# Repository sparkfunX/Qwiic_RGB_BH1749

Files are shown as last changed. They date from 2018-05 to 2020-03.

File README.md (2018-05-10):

SparkFun RGB Sensor (Qwiic) - BH1749NUC
========================================

SparkFun RGB Sensor (Qwiic) - BH1749NUC

[*SparkX RGB Sensor (Qwiic) - BH1749NUC (SPX-14733)*](https://www.sparkfun.com/products/14733)

Need to autonomously monitor for that specific color value? Want to hone in on that magenta ball? Or follow that aquamarine line? The BH1749NUC-based Qwiic RGB Sensor is here for all of your <span style="color:red">red</span>, <span style="color:green">green</span>, <span style="color:blue">blue</span>, and <span style="color:darkred">infrared</span> color-sensing needs.

The **BH1749NUC** features an I<sup>2</sup>C interface and a programmable interrupt output. It senses red, green, blue, and infrared in its field-of-view, then reports them as a 16-bit value. Additionally, it features programmable IR and RGB gains and a variable measurement rate. 

Also included on the breakout are individually-controllable white, red, green, and blue LEDs. The LEDs are managed with a **PCA9536** 4-channel I/O I<sup>2</sup>C expander. We've got a library for that too!

Check out the documents section for a pair of Arduino libraries -- for both the [BH1749NUC](https://github.com/sparkfun/SparkFun_BH1749NUC_Arduino_Library) and [PCA9536](https://github.com/sparkfun/SparkFun_PCA9536_Arduino_Library) IC's -- and a handful of examples to help get you started.

The Qwiic RGB Sensor uses our simple [Qwiic](https://www.sparkfun.com/qwiic) interface, so it requires no voltage translation and no figuring out which pin is SDA or SCL; just plug it in and go! As with any Qwiic board, this product includes a pair of Qwiic connectors to support a chain of multiple sensors.

SparkFun labored with love to create this code. Feel like supporting open source hardware? 
Buy a [breakout board](https://www.sparkfun.com/products/14733) from SparkFun!

Repository Contents
-------------------

* **/Documents** - Datasheets
* **/Hardware** - Eagle design files (.brd, .sch)

License Information
-------------------

This product is _**open source**_! 

If you have any questions or concerns on licensing, please contact techsupport@sparkfun.com.

Please use, reuse, and modify these files as you see fit. Please maintain attribution to SparkFun Electronics and release any derivative under the same license.

Distributed as-is; no warranty is given.

- Your friends at SparkFun.

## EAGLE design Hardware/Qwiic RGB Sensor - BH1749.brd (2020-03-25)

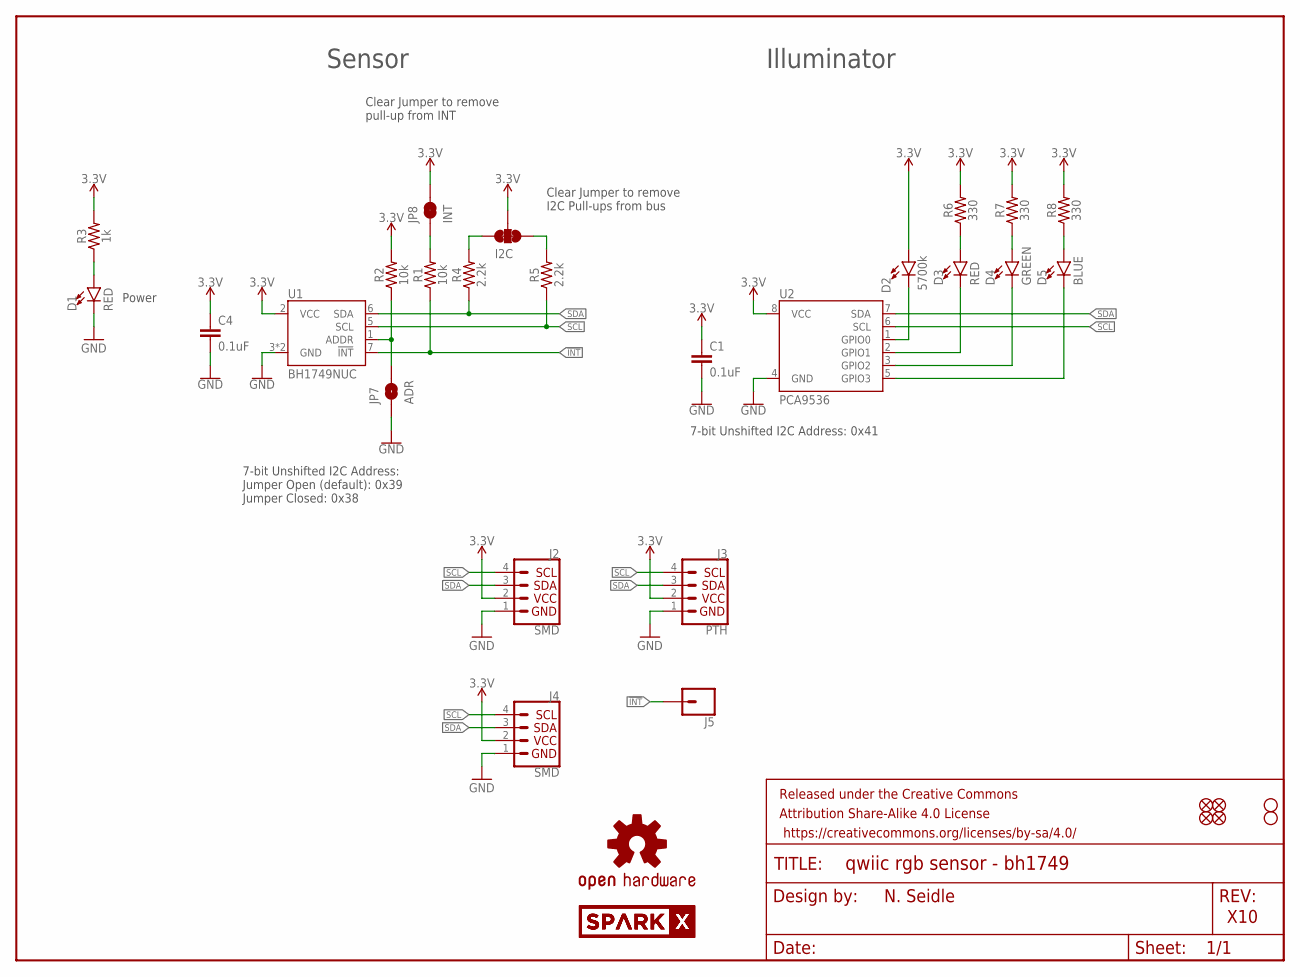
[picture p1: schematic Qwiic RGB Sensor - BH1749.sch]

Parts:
C1, C4: 0.1uF; 0603
D1, D3: RED; LED-0603
D2: 5700k; SUPER_BRIGHT_SMD_LED_1206
D4: GREEN; LED-0603
D5: BLUE; LED-0603
FRAME1: FRAME-LETTER; CREATIVE_COMMONS
I2C: JUMPER-SMT_3_2-NC_TRACE_SILK; SMT-JUMPER_3_2-NC_TRACE_SILK
J2, J4: SMD; 1X04_1MM_RA
J3: PTH; 1X04_NO_SILK
J5: CONN_01PTH_NO_SILK_YES_STOP; 1X01_NO_SILK
JP1, JP2, JP5, JP6: FIDUCIALUFIDUCIAL; MICRO-FIDUCIAL
JP3, JP4: STAND-OFF
JP7: ADR; SMT-JUMPER_2_NO_SILK
JP8: INT; SMT-JUMPER_2_NC_TRACE_SILK
LOGO1: OSHW-LOGOMINI; OSHW-LOGO-MINI
R1, R2: 10k; 0603
R3: 1k; 0603
R4, R5: 2.2k; 0603
R6, R7, R8: 330; 0603
U1: BH1749NUC
U2: PCA9536; MSOP8
U$1, U$2: SPARKX-LOGO4; SPARKX-MEDIUM

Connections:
3.3V: C1.1, C4.1, D2.A, I2C.2, J2.2 (VCC), J3.2 (VCC), J4.2 (VCC), JP8.2, R2.2, R3.2, R6.2, R7.2, R8.2, U1.2 (VCC), U2.8 (VCC)
!INT: J5.1, R1.1, U1.7 (!INT)
ADR: JP7.2, R2.1, U1.1 (ADDR)
GND: C1.2, C4.2, D1.C, J2.1 (GND), J3.1 (GND), J4.1 (GND), JP7.1, U1.3 (GND), U1.4 (GND), U2.4 (GND)
unnamed: I2C.1, R5.2
unnamed: I2C.3, R4.2
unnamed: D1.A, R3.1
unnamed: JP8.1, R1.2
unnamed: D3.C, U2.2 (GPIO1)
unnamed: D4.C, U2.3 (GPIO2)
unnamed: D5.C, U2.5 (GPIO3)
unnamed: D3.A, R6.1
unnamed: D4.A, R7.1
unnamed: D2.C, U2.1 (GPIO0)
unnamed: D5.A, R8.1
SCL: J2.4 (SCL), J3.4 (SCL), J4.4 (SCL), R5.1, U1.5 (SCL), U2.6 (SCL)
SDA: J2.3 (SDA), J3.3 (SDA), J4.3 (SDA), R4.1, U1.6 (SDA), U2.7 (SDA)

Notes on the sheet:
N. Seidle
X10
7-bit Unshifted I2C Address: Jumper Open (default): 0x39 Jumper Closed: 0x38
Clear Jumper to remove I2C Pull-ups from bus
Clear Jumper to remove pull-up from INT
Power
7-bit Unshifted I2C Address: 0x41
Sensor
Illuminator

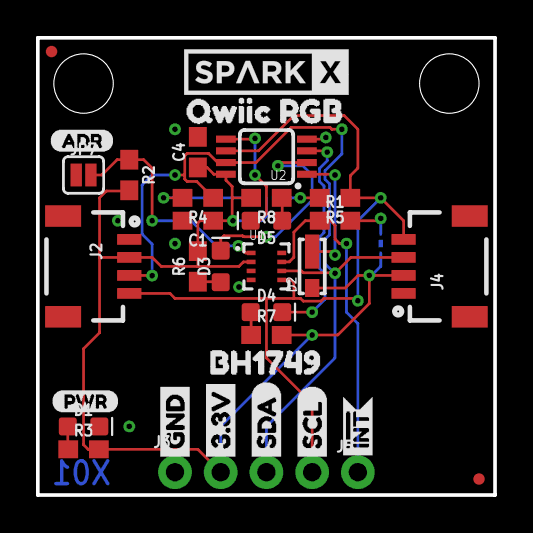
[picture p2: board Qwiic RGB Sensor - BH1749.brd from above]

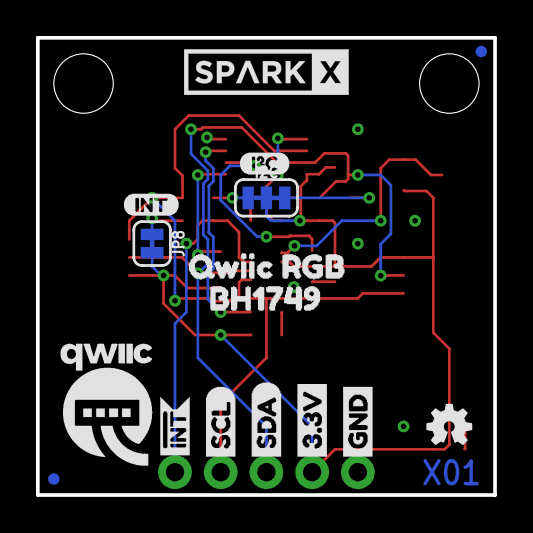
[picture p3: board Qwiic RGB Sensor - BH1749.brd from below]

Board: 2 copper layers, 25.4 x 25.4 mm, 53 parts (16 on the bottom side), 17 nets.

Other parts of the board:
U$3, U$22: GND1
U$4, U$21: 3#3V2
U$5, U$27: SDA8
U$6, U$26: SCL9
U$7, U$9: INT#-[<
U$8: QWIIC-LOGO-MEDIUM
U$10: I_SUPER2_C-()-03
U$11, U$13: BH17493
U$12, U$24: QWIIC_RGB2
U$16: PWR-()-03
U$17: ADR-()-03
U$20: INT0

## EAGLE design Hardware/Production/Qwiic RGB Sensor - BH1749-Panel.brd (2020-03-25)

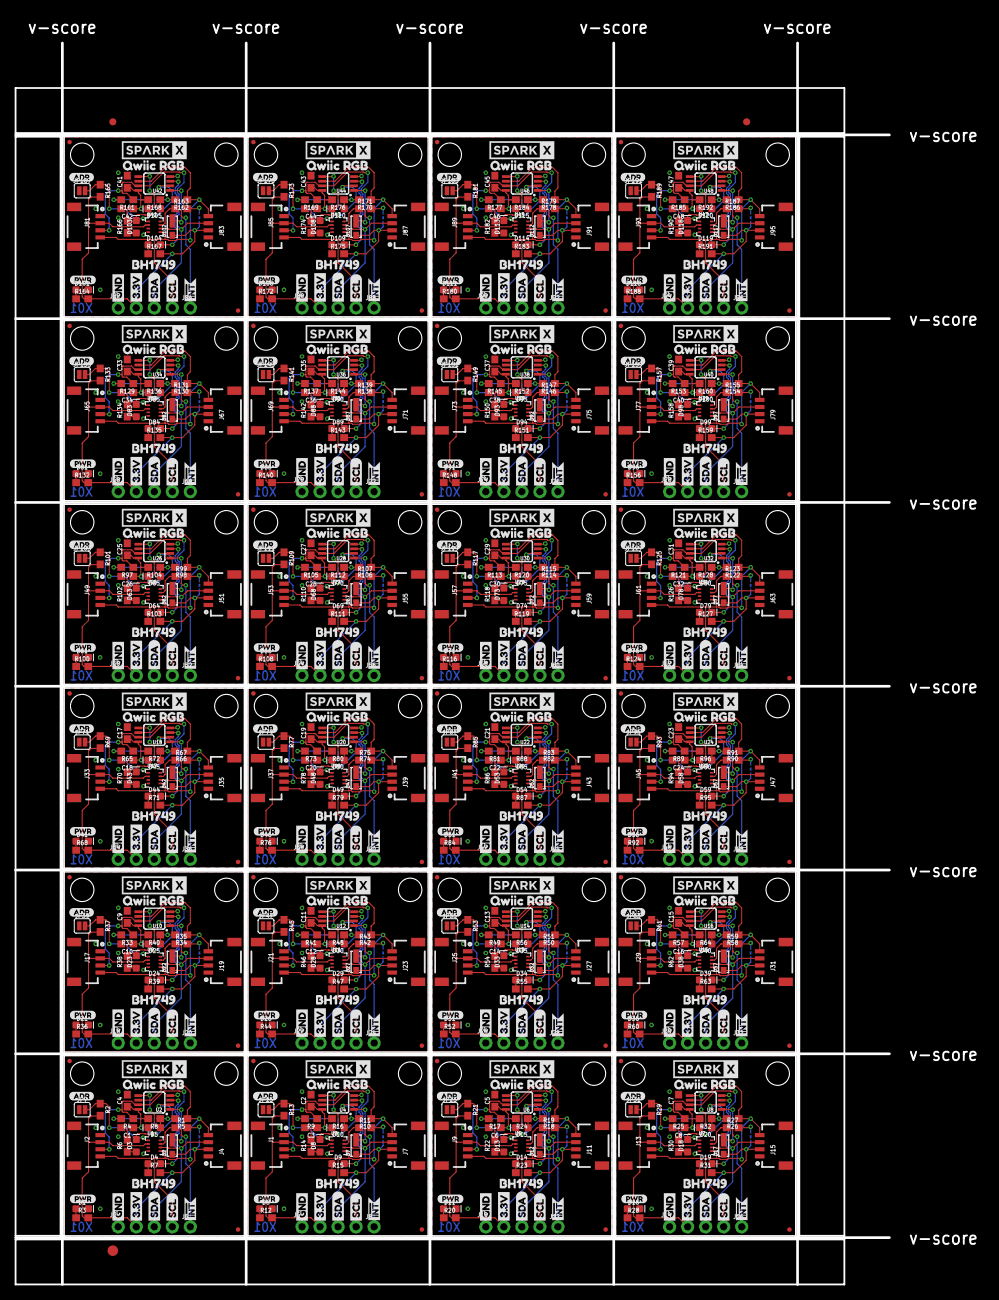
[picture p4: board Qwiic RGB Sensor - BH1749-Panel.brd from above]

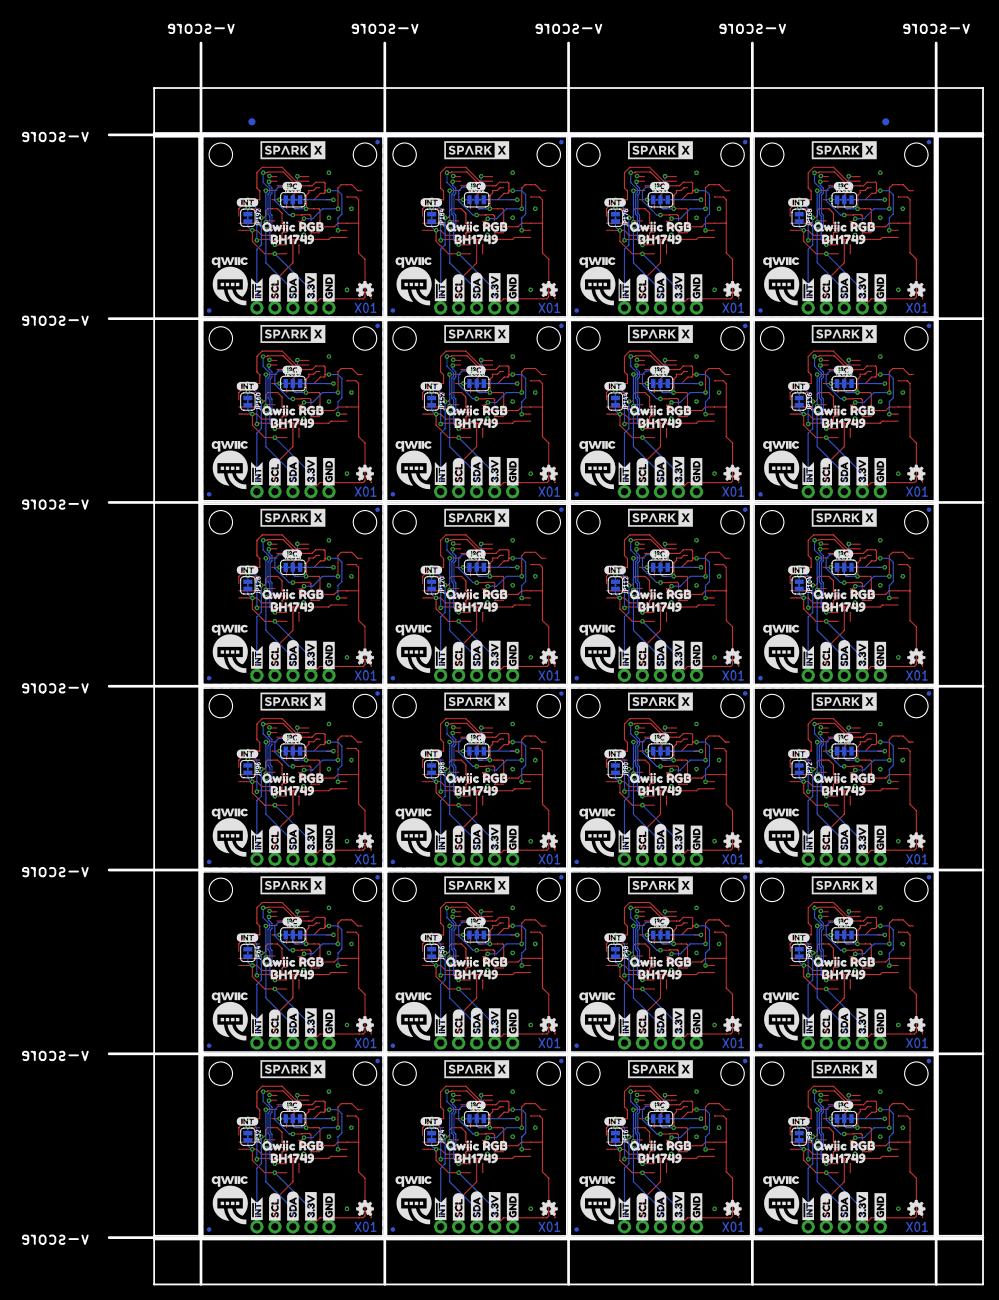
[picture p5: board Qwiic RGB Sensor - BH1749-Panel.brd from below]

Board: 2 copper layers, 123.2 x 175.0 mm, 1253 parts (386 on the bottom side), 408 nets.

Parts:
C1, C2, C3, C4, C5, C6, C7, C8, C9, C10, C11, C12, C13, C14, C15, C16, C17, C18, C19, C20, C21, C22, C23, C24, C25, C26, C27, C28, C29, C30, C31, C32, C33, C34, C35, C36, C37, C38, C39, C40, C41, C42, C43, C44, C45, C46, C47, C48: 0.1uF; 0603
D1, D3, D6, D8, D11, D13, D16, D18, D21, D23, D26, D28, D31, D33, D36, D38, D41, D43, D46, D48, D51, D53, D56, D58, D61, D63, D66, D68, D71, D73, D76, D78, D81, D83, D86, D88, D91, D93, D96, D98, D101, D103, D106, D108, D111, D113, D116, D118: RED; LED-0603
D2, D7, D12, D17, D22, D27, D32, D37, D42, D47, D52, D57, D62, D67, D72, D77, D82, D87, D92, D97, D102, D107, D112, D117: 5700k; SUPER_BRIGHT_SMD_LED_1206
D4, D9, D14, D19, D24, D29, D34, D39, D44, D49, D54, D59, D64, D69, D74, D79, D84, D89, D94, D99, D104, D109, D114, D119: GREEN; LED-0603
D5, D10, D15, D20, D25, D30, D35, D40, D45, D50, D55, D60, D65, D70, D75, D80, D85, D90, D95, D100, D105, D110, D115, D120: BLUE; LED-0603
E$1, E$2, E$3, E$4: FIDUCIAL-1X2
E$5: FIDUCIAL-1.5X3
I2C, I2C1, I2C2, I2C3, I2C4, I2C5, I2C6, I2C7, I2C8, I2C9, I2C10, I2C11, I2C12, I2C13, I2C14, I2C15, I2C16, I2C17, I2C18, I2C19, I2C20, I2C21, I2C22, I2C23: SMT-JUMPER_3_2-NC_TRACE_SILK
J1, J2, J4, J7, J9, J11, J13, J15, J17, J19, J21, J23, J25, J27, J29, J31, J33, J35, J37, J39, J41, J43, J45, J47, J49, J51, J53, J55, J57, J59, J61, J63, J65, J67, J69, J71, J73, J75, J77, J79, J81, J83, J85, J87, J89, J91, J93, J95: SMD; 1X04_1MM_RA
J3, J6, J10, J14, J18, J22, J26, J30, J34, J38, J42, J46, J50, J54, J58, J62, J66, J70, J74, J78, J82, J86, J90, J94: PTH; 1X04_NO_SILK
J5, J8, J12, J16, J20, J24, J28, J32, J36, J40, J44, J48, J52, J56, J60, J64, J68, J72, J76, J80, J84, J88, J92, J96: 1X01_NO_SILK
JP1, JP2, JP5, JP6, JP11, JP12, JP13, JP14, JP19, JP20, JP21, JP22, JP27, JP28, JP29, JP30, JP35, JP36, JP37, JP38, JP43, JP44, JP45, JP46, JP51, JP52, JP53, JP54, JP59, JP60, JP61, JP62, JP67, JP68, JP69, JP70, JP75, JP76, JP77, JP78, JP83, JP84, JP85, JP86, JP91, JP92, JP93, JP94, JP99, JP100, JP101, JP102, JP107, JP108, JP109, JP110, JP115, JP116, JP117, JP118, JP123, JP124, JP125, JP126, JP131, JP132, JP133, JP134, JP139, JP140, JP141, JP142, JP147, JP148, JP149, JP150, JP155, JP156, JP157, JP158, JP163, JP164, JP165, JP166, JP171, JP172, JP173, JP174, JP179, JP180, JP181, JP182, JP187, JP188, JP189, JP190: FIDUCIALUFIDUCIAL; MICRO-FIDUCIAL
JP3, JP4, JP9, JP10, JP17, JP18, JP25, JP26, JP33, JP34, JP41, JP42, JP49, JP50, JP57, JP58, JP65, JP66, JP73, JP74, JP81, JP82, JP89, JP90, JP97, JP98, JP105, JP106, JP113, JP114, JP121, JP122, JP129, JP130, JP137, JP138, JP145, JP146, JP153, JP154, JP161, JP162, JP169, JP170, JP177, JP178, JP185, JP186: STAND-OFF
JP7, JP15, JP23, JP31, JP39, JP47, JP55, JP63, JP71, JP79, JP87, JP95, JP103, JP111, JP119, JP127, JP135, JP143, JP151, JP159, JP167, JP175, JP183, JP191: ADR; SMT-JUMPER_2_NO_SILK
JP8, JP16, JP24, JP32, JP40, JP48, JP56, JP64, JP72, JP80, JP88, JP96, JP104, JP112, JP120, JP128, JP136, JP144, JP152, JP160, JP168, JP176, JP184, JP192: INT; SMT-JUMPER_2_NC_TRACE_SILK
LOGO1, LOGO2, LOGO3, LOGO4, LOGO5, LOGO6, LOGO7, LOGO8, LOGO9, LOGO10, LOGO11, LOGO12, LOGO13, LOGO14, LOGO15, LOGO16, LOGO17, LOGO18, LOGO19, LOGO20, LOGO21, LOGO22, LOGO23, LOGO24: OSHW-LOGOMINI; OSHW-LOGO-MINI
R1, R2, R11, R13, R19, R21, R27, R29, R35, R37, R43, R45, R51, R53, R59, R61, R67, R69, R75, R77, R83, R85, R91, R93, R99, R101, R107, R109, R115, R117, R123, R125, R131, R133, R139, R141, R147, R149, R155, R157, R163, R165, R171, R173, R179, R181, R187, R189: 10k; 0603
R3, R12, R20, R28, R36, R44, R52, R60, R68, R76, R84, R92, R100, R108, R116, R124, R132, R140, R148, R156, R164, R172, R180, R188: 1k; 0603
R4, R5, R9, R10, R17, R18, R25, R26, R33, R34, R41, R42, R49, R50, R57, R58, R65, R66, R73, R74, R81, R82, R89, R90, R97, R98, R105, R106, R113, R114, R121, R122, R129, R130, R137, R138, R145, R146, R153, R154, R161, R162, R169, R170, R177, R178, R185, R186: 2.2k; 0603
R6, R7, R8, R14, R15, R16, R22, R23, R24, R30, R31, R32, R38, R39, R40, R46, R47, R48, R54, R55, R56, R62, R63, R64, R70, R71, R72, R78, R79, R80, R86, R87, R88, R94, R95, R96, R102, R103, R104, R110, R111, R112, R118, R119, R120, R126, R127, R128, R134, R135, R136, R142, R143, R144, R150, R151, R152, R158, R159, R160, R166, R167, R168, R174, R175, R176, R182, R183, R184, R190, R191, R192: 330; 0603
U1, U3, U5, U7, U9, U11, U13, U15, U17, U19, U21, U23, U25, U27, U29, U31, U33, U35, U37, U39, U41, U43, U45, U47: BH1749NUC
U2, U4, U6, U8, U10, U12, U14, U16, U18, U20, U22, U24, U26, U28, U30, U32, U34, U36, U38, U40, U42, U44, U46, U48: PCA9536; MSOP8
U$1, U$2, U$14, U$15, U$43, U$44, U$64, U$65, U$85, U$86, U$106, U$107, U$127, U$128, U$148, U$149, U$169, U$170, U$190, U$191, U$211, U$212, U$232, U$233, U$253, U$254, U$274, U$275, U$295, U$296, U$316, U$317, U$337, U$338, U$358, U$359, U$379, U$380, U$400, U$401, U$421, U$422, U$442, U$443, U$463, U$464, U$484, U$485: SPARKX-LOGO4; SPARKX-MEDIUM
U$3, U$19, U$22, U$28, U$46, U$49, U$67, U$70, U$88, U$91, U$109, U$112, U$130, U$133, U$151, U$154, U$172, U$175, U$193, U$196, U$214, U$217, U$235, U$238, U$256, U$259, U$277, U$280, U$298, U$301, U$319, U$322, U$340, U$343, U$361, U$364, U$382, U$385, U$403, U$406, U$424, U$427, U$445, U$448, U$466, U$469, U$487, U$490: GND1
U$4, U$18, U$21, U$29, U$45, U$50, U$66, U$71, U$87, U$92, U$108, U$113, U$129, U$134, U$150, U$155, U$171, U$176, U$192, U$197, U$213, U$218, U$234, U$239, U$255, U$260, U$276, U$281, U$297, U$302, U$318, U$323, U$339, U$344, U$360, U$365, U$381, U$386, U$402, U$407, U$423, U$428, U$444, U$449, U$465, U$470, U$486, U$491: 3#3V2
U$5, U$25, U$27, U$30, U$48, U$51, U$69, U$72, U$90, U$93, U$111, U$114, U$132, U$135, U$153, U$156, U$174, U$177, U$195, U$198, U$216, U$219, U$237, U$240, U$258, U$261, U$279, U$282, U$300, U$303, U$321, U$324, U$342, U$345, U$363, U$366, U$384, U$387, U$405, U$408, U$426, U$429, U$447, U$450, U$468, U$471, U$489, U$492: SDA8
U$6, U$23, U$26, U$31, U$47, U$52, U$68, U$73, U$89, U$94, U$110, U$115, U$131, U$136, U$152, U$157, U$173, U$178, U$194, U$199, U$215, U$220, U$236, U$241, U$257, U$262, U$278, U$283, U$299, U$304, U$320, U$325, U$341, U$346, U$362, U$367, U$383, U$388, U$404, U$409, U$425, U$430, U$446, U$451, U$467, U$472, U$488, U$493: SCL9
U$7, U$9, U$33, U$34, U$54, U$55, U$75, U$76, U$96, U$97, U$117, U$118, U$138, U$139, U$159, U$160, U$180, U$181, U$201, U$202, U$222, U$223, U$243, U$244, U$264, U$265, U$285, U$286, U$306, U$307, U$327, U$328, U$348, U$349, U$369, U$370, U$390, U$391, U$411, U$412, U$432, U$433, U$453, U$454, U$474, U$475, U$495, U$496: INT#-[<
U$8, U$32, U$53, U$74, U$95, U$116, U$137, U$158, U$179, U$200, U$221, U$242, U$263, U$284, U$305, U$326, U$347, U$368, U$389, U$410, U$431, U$452, U$473, U$494: QWIIC-LOGO-MEDIUM
U$10, U$37, U$58, U$79, U$100, U$121, U$142, U$163, U$184, U$205, U$226, U$247, U$268, U$289, U$310, U$331, U$352, U$373, U$394, U$415, U$436, U$457, U$478, U$499: I_SUPER2_C-()-03
U$11, U$13, U$38, U$42, U$59, U$63, U$80, U$84, U$101, U$105, U$122, U$126, U$143, U$147, U$164, U$168, U$185, U$189, U$206, U$210, U$227, U$231, U$248, U$252, U$269, U$273, U$290, U$294, U$311, U$315, U$332, U$336, U$353, U$357, U$374, U$378, U$395, U$399, U$416, U$420, U$437, U$441, U$458, U$462, U$479, U$483, U$500, U$504: BH17493
U$12, U$24, U$40, U$41, U$61, U$62, U$82, U$83, U$103, U$104, U$124, U$125, U$145, U$146, U$166, U$167, U$187, U$188, U$208, U$209, U$229, U$230, U$250, U$251, U$271, U$272, U$292, U$293, U$313, U$314, U$334, U$335, U$355, U$356, U$376, U$377, U$397, U$398, U$418, U$419, U$439, U$440, U$460, U$461, U$481, U$482, U$502, U$503: QWIIC_RGB2
U$16, U$35, U$56, U$77, U$98, U$119, U$140, U$161, U$182, U$203, U$224, U$245, U$266, U$287, U$308, U$329, U$350, U$371, U$392, U$413, U$434, U$455, U$476, U$497: PWR-()-03
U$17, U$36, U$57, U$78, U$99, U$120, U$141, U$162, U$183, U$204, U$225, U$246, U$267, U$288, U$309, U$330, U$351, U$372, U$393, U$414, U$435, U$456, U$477, U$498: ADR-()-03
U$20, U$39, U$60, U$81, U$102, U$123, U$144, U$165, U$186, U$207, U$228, U$249, U$270, U$291, U$312, U$333, U$354, U$375, U$396, U$417, U$438, U$459, U$480, U$501: INT0

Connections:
3.3V: C1.1, C4.1, D2.A, I2C.2, J2.2, J3.2, J4.2, JP8.2, R2.2, R3.2, R6.2, R7.2, R8.2, U1.2, U2.8
3.3V1: C2.1, C3.1, D7.A, I2C1.2, J1.2, J6.2, J7.2, JP16.2, R12.2, R13.2, R14.2, R15.2, R16.2, U3.2, U4.8
3.3V2: C5.1, C6.1, D12.A, I2C2.2, J9.2, J10.2, J11.2, JP24.2, R20.2, R21.2, R22.2, R23.2, R24.2, U5.2, U6.8
3.3V3: C7.1, C8.1, D17.A, I2C3.2, J13.2, J14.2, J15.2, JP32.2, R28.2, R29.2, R30.2, R31.2, R32.2, U7.2, U8.8
3.3V4: C9.1, C10.1, D22.A, I2C4.2, J17.2, J18.2, J19.2, JP40.2, R36.2, R37.2, R38.2, R39.2, R40.2, U9.2, U10.8
3.3V5: C11.1, C12.1, D27.A, I2C5.2, J21.2, J22.2, J23.2, JP48.2, R44.2, R45.2, R46.2, R47.2, R48.2, U11.2, U12.8
3.3V6: C13.1, C14.1, D32.A, I2C6.2, J25.2, J26.2, J27.2, JP56.2, R52.2, R53.2, R54.2, R55.2, R56.2, U13.2, U14.8
3.3V7: C15.1, C16.1, D37.A, I2C7.2, J29.2, J30.2, J31.2, JP64.2, R60.2, R61.2, R62.2, R63.2, R64.2, U15.2, U16.8
3.3V8: C17.1, C18.1, D42.A, I2C8.2, J33.2, J34.2, J35.2, JP72.2, R68.2, R69.2, R70.2, R71.2, R72.2, U17.2, U18.8
3.3V9: C19.1, C20.1, D47.A, I2C9.2, J37.2, J38.2, J39.2, JP80.2, R76.2, R77.2, R78.2, R79.2, R80.2, U19.2, U20.8
3.3V10: C21.1, C22.1, D52.A, I2C10.2, J41.2, J42.2, J43.2, JP88.2, R84.2, R85.2, R86.2, R87.2, R88.2, U21.2, U22.8
3.3V11: C23.1, C24.1, D57.A, I2C11.2, J45.2, J46.2, J47.2, JP96.2, R92.2, R93.2, R94.2, R95.2, R96.2, U23.2, U24.8
3.3V12: C25.1, C26.1, D62.A, I2C12.2, J49.2, J50.2, J51.2, JP104.2, R100.2, R101.2, R102.2, R103.2, R104.2, U25.2, U26.8
3.3V13: C27.1, C28.1, D67.A, I2C13.2, J53.2, J54.2, J55.2, JP112.2, R108.2, R109.2, R110.2, R111.2, R112.2, U27.2, U28.8
3.3V14: C29.1, C30.1, D72.A, I2C14.2, J57.2, J58.2, J59.2, JP120.2, R116.2, R117.2, R118.2, R119.2, R120.2, U29.2, U30.8
3.3V15: C31.1, C32.1, D77.A, I2C15.2, J61.2, J62.2, J63.2, JP128.2, R124.2, R125.2, R126.2, R127.2, R128.2, U31.2, U32.8
3.3V16: C33.1, C34.1, D82.A, I2C16.2, J65.2, J66.2, J67.2, JP136.2, R132.2, R133.2, R134.2, R135.2, R136.2, U33.2, U34.8
3.3V17: C35.1, C36.1, D87.A, I2C17.2, J69.2, J70.2, J71.2, JP144.2, R140.2, R141.2, R142.2, R143.2, R144.2, U35.2, U36.8
3.3V18: C37.1, C38.1, D92.A, I2C18.2, J73.2, J74.2, J75.2, JP152.2, R148.2, R149.2, R150.2, R151.2, R152.2, U37.2, U38.8
3.3V19: C39.1, C40.1, D97.A, I2C19.2, J77.2, J78.2, J79.2, JP160.2, R156.2, R157.2, R158.2, R159.2, R160.2, U39.2, U40.8
3.3V20: C41.1, C42.1, D102.A, I2C20.2, J81.2, J82.2, J83.2, JP168.2, R164.2, R165.2, R166.2, R167.2, R168.2, U41.2, U42.8
3.3V21: C43.1, C44.1, D107.A, I2C21.2, J85.2, J86.2, J87.2, JP176.2, R172.2, R173.2, R174.2, R175.2, R176.2, U43.2, U44.8
3.3V22: C45.1, C46.1, D112.A, I2C22.2, J89.2, J90.2, J91.2, JP184.2, R180.2, R181.2, R182.2, R183.2, R184.2, U45.2, U46.8
3.3V23: C47.1, C48.1, D117.A, I2C23.2, J93.2, J94.2, J95.2, JP192.2, R188.2, R189.2, R190.2, R191.2, R192.2, U47.2, U48.8
!INT: J5.1, R1.1, U1.7
!INT1: J8.1, R11.1, U3.7
!INT2: J12.1, R19.1, U5.7
!INT3: J16.1, R27.1, U7.7
!INT4: J20.1, R35.1, U9.7
!INT5: J24.1, R43.1, U11.7
!INT6: J28.1, R51.1, U13.7
!INT7: J32.1, R59.1, U15.7
!INT8: J36.1, R67.1, U17.7
!INT9: J40.1, R75.1, U19.7
!INT10: J44.1, R83.1, U21.7
!INT11: J48.1, R91.1, U23.7
!INT12: J52.1, R99.1, U25.7
!INT13: J56.1, R107.1, U27.7
!INT14: J60.1, R115.1, U29.7
!INT15: J64.1, R123.1, U31.7
!INT16: J68.1, R131.1, U33.7
!INT17: J72.1, R139.1, U35.7
!INT18: J76.1, R147.1, U37.7
!INT19: J80.1, R155.1, U39.7
!INT20: J84.1, R163.1, U41.7
!INT21: J88.1, R171.1, U43.7
!INT22: J92.1, R179.1, U45.7
!INT23: J96.1, R187.1, U47.7
ADR: JP7.2, R2.1, U1.1
ADR1: JP15.2, R13.1, U3.1
ADR2: JP23.2, R21.1, U5.1
ADR3: JP31.2, R29.1, U7.1
ADR4: JP39.2, R37.1, U9.1
ADR5: JP47.2, R45.1, U11.1
ADR6: JP55.2, R53.1, U13.1
ADR7: JP63.2, R61.1, U15.1
ADR8: JP71.2, R69.1, U17.1
ADR9: JP79.2, R77.1, U19.1
ADR10: JP87.2, R85.1, U21.1
ADR11: JP95.2, R93.1, U23.1
ADR12: JP103.2, R101.1, U25.1
ADR13: JP111.2, R109.1, U27.1
ADR14: JP119.2, R117.1, U29.1
ADR15: JP127.2, R125.1, U31.1
ADR16: JP135.2, R133.1, U33.1
ADR17: JP143.2, R141.1, U35.1
ADR18: JP151.2, R149.1, U37.1
ADR19: JP159.2, R157.1, U39.1
ADR20: JP167.2, R165.1, U41.1
ADR21: JP175.2, R173.1, U43.1
ADR22: JP183.2, R181.1, U45.1
ADR23: JP191.2, R189.1, U47.1
GND: C1.2, C4.2, D1.C, J2.1, J3.1, J4.1, JP7.1, U1.3, U1.4, U2.4
GND1: C2.2, C3.2, D6.C, J1.1, J6.1, J7.1, JP15.1, U3.3, U3.4, U4.4
GND2: C5.2, C6.2, D11.C, J9.1, J10.1, J11.1, JP23.1, U5.3, U5.4, U6.4
GND3: C7.2, C8.2, D16.C, J13.1, J14.1, J15.1, JP31.1, U7.3, U7.4, U8.4
GND4: C9.2, C10.2, D21.C, J17.1, J18.1, J19.1, JP39.1, U9.3, U9.4, U10.4
GND5: C11.2, C12.2, D26.C, J21.1, J22.1, J23.1, JP47.1, U11.3, U11.4, U12.4
GND6: C13.2, C14.2, D31.C, J25.1, J26.1, J27.1, JP55.1, U13.3, U13.4, U14.4
GND7: C15.2, C16.2, D36.C, J29.1, J30.1, J31.1, JP63.1, U15.3, U15.4, U16.4
GND8: C17.2, C18.2, D41.C, J33.1, J34.1, J35.1, JP71.1, U17.3, U17.4, U18.4
GND9: C19.2, C20.2, D46.C, J37.1, J38.1, J39.1, JP79.1, U19.3, U19.4, U20.4
GND10: C21.2, C22.2, D51.C, J41.1, J42.1, J43.1, JP87.1, U21.3, U21.4, U22.4
GND11: C23.2, C24.2, D56.C, J45.1, J46.1, J47.1, JP95.1, U23.3, U23.4, U24.4
GND12: C25.2, C26.2, D61.C, J49.1, J50.1, J51.1, JP103.1, U25.3, U25.4, U26.4
GND13: C27.2, C28.2, D66.C, J53.1, J54.1, J55.1, JP111.1, U27.3, U27.4, U28.4
GND14: C29.2, C30.2, D71.C, J57.1, J58.1, J59.1, JP119.1, U29.3, U29.4, U30.4
GND15: C31.2, C32.2, D76.C, J61.1, J62.1, J63.1, JP127.1, U31.3, U31.4, U32.4
GND16: C33.2, C34.2, D81.C, J65.1, J66.1, J67.1, JP135.1, U33.3, U33.4, U34.4
GND17: C35.2, C36.2, D86.C, J69.1, J70.1, J71.1, JP143.1, U35.3, U35.4, U36.4
GND18: C37.2, C38.2, D91.C, J73.1, J74.1, J75.1, JP151.1, U37.3, U37.4, U38.4
GND19: C39.2, C40.2, D96.C, J77.1, J78.1, J79.1, JP159.1, U39.3, U39.4, U40.4
GND20: C41.2, C42.2, D101.C, J81.1, J82.1, J83.1, JP167.1, U41.3, U41.4, U42.4
GND21: C43.2, C44.2, D106.C, J85.1, J86.1, J87.1, JP175.1, U43.3, U43.4, U44.4
GND22: C45.2, C46.2, D111.C, J89.1, J90.1, J91.1, JP183.1, U45.3, U45.4, U46.4
GND23: C47.2, C48.2, D116.C, J93.1, J94.1, J95.1, JP191.1, U47.3, U47.4, U48.4
unnamed: I2C.1, R5.2
unnamed: I2C.3, R4.2
unnamed: D1.A, R3.1
unnamed: JP8.1, R1.2
unnamed: D3.C, U2.2
unnamed: D4.C, U2.3
unnamed: D5.C, U2.5
unnamed: D3.A, R6.1
unnamed: D4.A, R7.1
unnamed: D2.C, U2.1
unnamed: D5.A, R8.1
unnamed: I2C1.1, R10.2
unnamed: I2C1.3, R9.2
unnamed: JP16.1, R11.2
unnamed: D6.A, R12.1
unnamed: D7.C, U4.1
unnamed: D8.C, U4.2
unnamed: D9.C, U4.3
unnamed: D10.C, U4.5
unnamed: D8.A, R14.1
unnamed: D9.A, R15.1
unnamed: D10.A, R16.1
unnamed: I2C2.1, R18.2
unnamed: I2C2.3, R17.2
unnamed: JP24.1, R19.2
unnamed: D11.A, R20.1
unnamed: D12.C, U6.1
unnamed: D13.C, U6.2
unnamed: D14.C, U6.3
unnamed: D15.C, U6.5
unnamed: D13.A, R22.1
unnamed: D14.A, R23.1
unnamed: D15.A, R24.1
unnamed: I2C3.1, R26.2
unnamed: I2C3.3, R25.2
unnamed: JP32.1, R27.2
unnamed: D16.A, R28.1
unnamed: D17.C, U8.1
unnamed: D18.C, U8.2
unnamed: D19.C, U8.3
unnamed: D20.C, U8.5
unnamed: D18.A, R30.1
unnamed: D19.A, R31.1
unnamed: D20.A, R32.1
unnamed: I2C4.1, R34.2
unnamed: I2C4.3, R33.2
unnamed: JP40.1, R35.2
unnamed: D21.A, R36.1
unnamed: D22.C, U10.1
unnamed: D23.C, U10.2
unnamed: D24.C, U10.3
unnamed: D25.C, U10.5
unnamed: D23.A, R38.1
unnamed: D24.A, R39.1
unnamed: D25.A, R40.1
unnamed: I2C5.1, R42.2
unnamed: I2C5.3, R41.2
unnamed: JP48.1, R43.2
unnamed: D26.A, R44.1
unnamed: D27.C, U12.1
unnamed: D28.C, U12.2
unnamed: D29.C, U12.3
unnamed: D30.C, U12.5
unnamed: D28.A, R46.1
unnamed: D29.A, R47.1
unnamed: D30.A, R48.1
unnamed: I2C6.1, R50.2
unnamed: I2C6.3, R49.2
unnamed: JP56.1, R51.2
unnamed: D31.A, R52.1
unnamed: D32.C, U14.1
unnamed: D33.C, U14.2
unnamed: D34.C, U14.3
unnamed: D35.C, U14.5
unnamed: D33.A, R54.1
unnamed: D34.A, R55.1
unnamed: D35.A, R56.1
unnamed: I2C7.1, R58.2
unnamed: I2C7.3, R57.2
unnamed: JP64.1, R59.2
unnamed: D36.A, R60.1
unnamed: D37.C, U16.1
unnamed: D38.C, U16.2
unnamed: D39.C, U16.3
unnamed: D40.C, U16.5
unnamed: D38.A, R62.1
unnamed: D39.A, R63.1
unnamed: D40.A, R64.1
unnamed: I2C8.1, R66.2
unnamed: I2C8.3, R65.2
unnamed: JP72.1, R67.2
unnamed: D41.A, R68.1
unnamed: D42.C, U18.1
unnamed: D43.C, U18.2
unnamed: D44.C, U18.3
unnamed: D45.C, U18.5
unnamed: D43.A, R70.1
unnamed: D44.A, R71.1
unnamed: D45.A, R72.1
unnamed: I2C9.1, R74.2
unnamed: I2C9.3, R73.2
unnamed: JP80.1, R75.2
unnamed: D46.A, R76.1
unnamed: D47.C, U20.1
unnamed: D48.C, U20.2
unnamed: D49.C, U20.3
unnamed: D50.C, U20.5
unnamed: D48.A, R78.1
unnamed: D49.A, R79.1
unnamed: D50.A, R80.1
unnamed: I2C10.1, R82.2
unnamed: I2C10.3, R81.2
unnamed: JP88.1, R83.2
unnamed: D51.A, R84.1
unnamed: D52.C, U22.1
unnamed: D53.C, U22.2
unnamed: D54.C, U22.3
unnamed: D55.C, U22.5
unnamed: D53.A, R86.1
unnamed: D54.A, R87.1
unnamed: D55.A, R88.1
unnamed: I2C11.1, R90.2
unnamed: I2C11.3, R89.2
unnamed: JP96.1, R91.2
unnamed: D56.A, R92.1
unnamed: D57.C, U24.1
unnamed: D58.C, U24.2
unnamed: D59.C, U24.3
unnamed: D60.C, U24.5
unnamed: D58.A, R94.1
unnamed: D59.A, R95.1
unnamed: D60.A, R96.1
unnamed: I2C12.1, R98.2
unnamed: I2C12.3, R97.2
unnamed: JP104.1, R99.2
unnamed: D61.A, R100.1
unnamed: D62.C, U26.1
unnamed: D63.C, U26.2
unnamed: D64.C, U26.3
unnamed: D65.C, U26.5
unnamed: D63.A, R102.1
unnamed: D64.A, R103.1
unnamed: D65.A, R104.1
unnamed: I2C13.1, R106.2
unnamed: I2C13.3, R105.2
unnamed: JP112.1, R107.2
unnamed: D66.A, R108.1
unnamed: D67.C, U28.1
unnamed: D68.C, U28.2
unnamed: D69.C, U28.3
unnamed: D70.C, U28.5
unnamed: D68.A, R110.1
unnamed: D69.A, R111.1
unnamed: D70.A, R112.1
unnamed: I2C14.1, R114.2
unnamed: I2C14.3, R113.2
unnamed: JP120.1, R115.2
unnamed: D71.A, R116.1
unnamed: D72.C, U30.1
unnamed: D73.C, U30.2
unnamed: D74.C, U30.3
unnamed: D75.C, U30.5
unnamed: D73.A, R118.1
unnamed: D74.A, R119.1
unnamed: D75.A, R120.1
unnamed: I2C15.1, R122.2
unnamed: I2C15.3, R121.2
unnamed: JP128.1, R123.2
unnamed: D76.A, R124.1
unnamed: D77.C, U32.1
unnamed: D78.C, U32.2
unnamed: D79.C, U32.3
unnamed: D80.C, U32.5
unnamed: D78.A, R126.1
unnamed: D79.A, R127.1
unnamed: D80.A, R128.1
unnamed: I2C16.1, R130.2
unnamed: I2C16.3, R129.2
unnamed: JP136.1, R131.2
unnamed: D81.A, R132.1
unnamed: D82.C, U34.1
unnamed: D83.C, U34.2
unnamed: D84.C, U34.3
unnamed: D85.C, U34.5
unnamed: D83.A, R134.1
unnamed: D84.A, R135.1
unnamed: D85.A, R136.1
unnamed: I2C17.1, R138.2
unnamed: I2C17.3, R137.2
unnamed: JP144.1, R139.2
unnamed: D86.A, R140.1
unnamed: D87.C, U36.1
unnamed: D88.C, U36.2
unnamed: D89.C, U36.3
unnamed: D90.C, U36.5
unnamed: D88.A, R142.1
unnamed: D89.A, R143.1
unnamed: D90.A, R144.1
unnamed: I2C18.1, R146.2
unnamed: I2C18.3, R145.2
unnamed: JP152.1, R147.2
unnamed: D91.A, R148.1
unnamed: D92.C, U38.1
unnamed: D93.C, U38.2
unnamed: D94.C, U38.3
unnamed: D95.C, U38.5
unnamed: D93.A, R150.1
unnamed: D94.A, R151.1
unnamed: D95.A, R152.1
unnamed: I2C19.1, R154.2
unnamed: I2C19.3, R153.2
unnamed: JP160.1, R155.2
unnamed: D96.A, R156.1
unnamed: D97.C, U40.1
unnamed: D98.C, U40.2
unnamed: D99.C, U40.3
unnamed: D100.C, U40.5
unnamed: D98.A, R158.1
unnamed: D99.A, R159.1
unnamed: D100.A, R160.1
unnamed: I2C20.1, R162.2
unnamed: I2C20.3, R161.2
unnamed: JP168.1, R163.2
unnamed: D101.A, R164.1
unnamed: D102.C, U42.1
unnamed: D103.C, U42.2
unnamed: D104.C, U42.3
unnamed: D105.C, U42.5
unnamed: D103.A, R166.1
unnamed: D104.A, R167.1
unnamed: D105.A, R168.1
unnamed: I2C21.1, R170.2
unnamed: I2C21.3, R169.2
unnamed: JP176.1, R171.2
unnamed: D106.A, R172.1
unnamed: D107.C, U44.1
unnamed: D108.C, U44.2
unnamed: D109.C, U44.3
unnamed: D110.C, U44.5
unnamed: D108.A, R174.1
unnamed: D109.A, R175.1
unnamed: D110.A, R176.1
unnamed: I2C22.1, R178.2
unnamed: I2C22.3, R177.2
unnamed: JP184.1, R179.2
unnamed: D111.A, R180.1
unnamed: D112.C, U46.1
unnamed: D113.C, U46.2
unnamed: D114.C, U46.3
unnamed: D115.C, U46.5
unnamed: D113.A, R182.1
unnamed: D114.A, R183.1
unnamed: D115.A, R184.1
unnamed: I2C23.1, R186.2
unnamed: I2C23.3, R185.2
unnamed: JP192.1, R187.2
unnamed: D116.A, R188.1
unnamed: D117.C, U48.1
unnamed: D118.C, U48.2
unnamed: D119.C, U48.3
unnamed: D120.C, U48.5
unnamed: D118.A, R190.1
unnamed: D119.A, R191.1
unnamed: D120.A, R192.1
SCL: J2.4, J3.4, J4.4, R5.1, U1.5, U2.6
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

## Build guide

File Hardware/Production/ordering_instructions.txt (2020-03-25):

panel size, 117x162mm
PCB thickness, 1.6mm
number of layers, 2
soldermask color, Black
silkscreen color, White
oz copper, 1oz
finish, HASL lead free
stencils, top+bottom
pcs per panel, 24
min trace width, 0.1524mm / 0.0060in
min drill size, 0.3048mm / 0.0120in

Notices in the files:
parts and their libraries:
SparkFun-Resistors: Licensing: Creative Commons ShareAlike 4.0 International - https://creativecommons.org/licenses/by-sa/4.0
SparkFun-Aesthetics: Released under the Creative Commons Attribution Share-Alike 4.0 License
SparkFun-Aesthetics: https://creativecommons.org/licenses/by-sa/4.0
